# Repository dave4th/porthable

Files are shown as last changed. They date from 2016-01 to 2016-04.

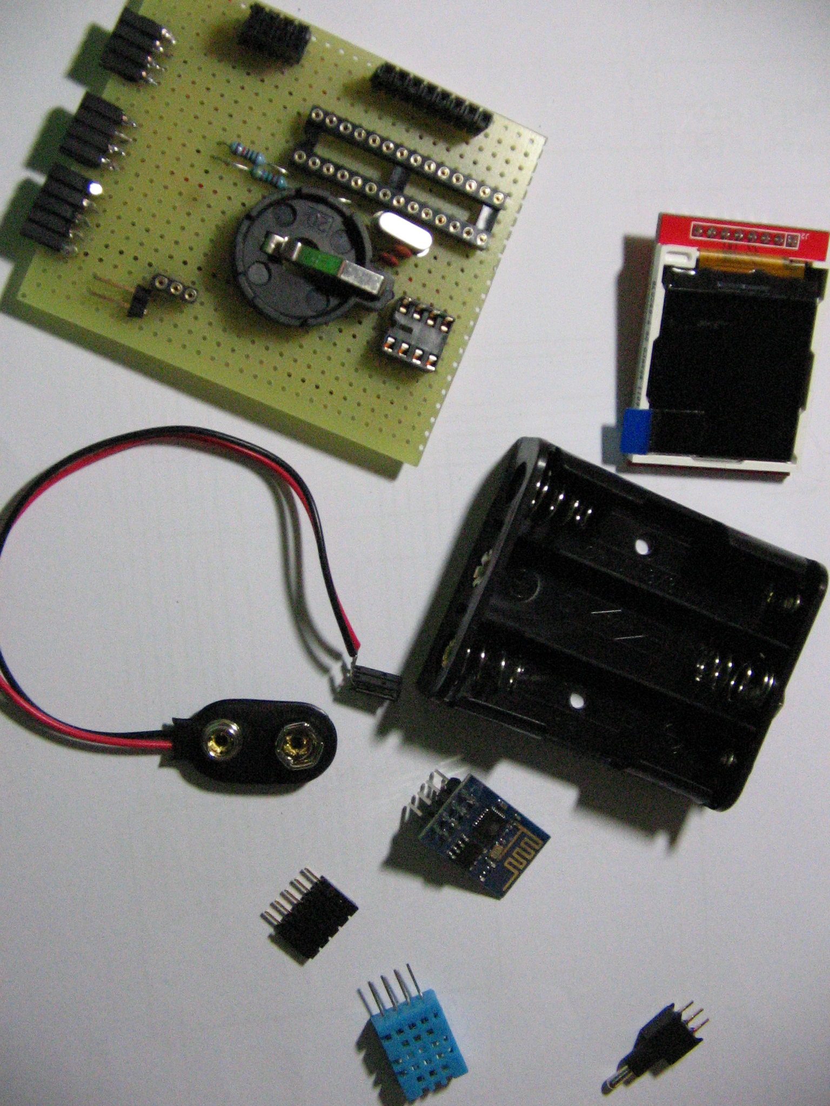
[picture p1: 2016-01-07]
foto/Porthable_beta_components_1.jpg

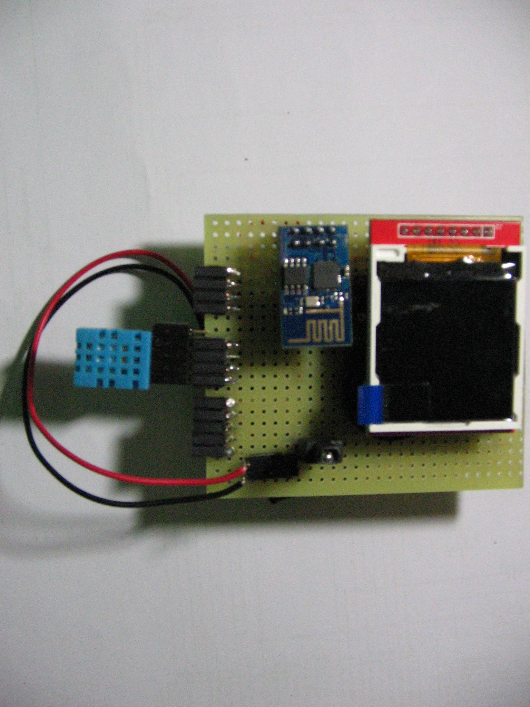
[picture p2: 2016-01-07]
foto/Porthable_beta_2nd_mount.jpg

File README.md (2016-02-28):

ATTENZIONE
==========
Il progetto e` in corso, le informazioni contenute in questo repository sono inesatte ed incomplete.

# porthable
Portabile (?) "logger" di temperatura e umidita` con LCD e mdulo ESP8266

Un piccolo esperimento per realizzare un sensore di temperatura che sia movibile per rilevazioni temporanee, che memorizzi le variazioni in un grafico e trasmetta o permetta di leggere da remoto i valori.

Poi .. vedremo in cosa e se .. si evolvera`.

## Composizione/i
* ATMEGA328P (Arduino)
* Sonda temperatura:
    * Sonda di temperatura e umidita` DHT11
    * Sonda di temperatura DS18B20
* TFT LCD 1,44"
* Modulo wifi ESP8266
* Modulo orologio DS1302

# Kicad

Il circuito e` aggiornato (se non ho dimenticato di fare upload ;) ), normalmente anche il ".pdf", per il resto, estrazione materiali, pcb .. eccetera, sono solo delle prove.

# w/ DS1302

Nei 'moduli' con orologio, per prima cosa si deve configurare l'ora, dopo aver collegato all'ATMEGA il DS1302 come da circuito elettrico, caricare sul microcontrollore il programma: "porthable_DS1302_SetSerial".

### Problema DS1302

Se si sostituisce l'atmega (per esempio quando se ne mette uno programmato differente) togliendo completamente alimentazione, lsciando comunque la batteria tampone, il DS1302 sembra vada in blocco e si deve riprogrammare.

Sembra sia sufficiente mantenere alimentazione (o meglio, mantenere il riferimento a 0V) aprendo solo l'interruttore di accensione, quando si sostituisce l'atmega.

## Programmazione con Raspberry Pi

Anzitutto ho creato il ".hex" semplicemente facendo un verifica dall'Arduino IDE 1.6.7, il file viene generato in una sottodirectory "/tmp".

Prima di caricare il programma, scollegate/togliete il Display (perche\` ha dei collegamenti in comune sulla SPI) e il modulo ESP8266 (perche\` e\` collegato sulla seriale), se li avete collegati.

Caricare lo sketch col comando (non serve avere un'ATMEGA col bootloader precaricato):
<pre>sudo avrdude -p m328p -P /dev/spidev0.0 -c linuxspi -b 10000 -U flash:w:git/porthable/arduino/porthable_DS1302_SetSerial.ino.hex</pre>

Con le "python-serial" (http://pyserial.readthedocs.org/en/latest/tools.html#module-serial.tools.miniterm) ho configurato l'ora:
<pre>miniterm.py --cr /dev/ttyAMA0 115200</pre>

Le istruzioni su come procedere all'impostazione dell'ora sono indicate nel ".ino" (che contiene il codice sorgente), comunque basta inserire la stringa "aaaa,mm,gg,HH,MM,SS" (Anno,Mese,Giorno,Hora,Minuti,Secondi).

Questa operazione dovra\` essere ripetuta quando si scarichera` la batteria tampone.

Ora potete procedere caricando sull'ATMEGA il programma vero e proprio ...

# porthable ADLD

Prima versione, composta da:
* ATMEGA328P
* DHT11
* LCD TFT 1,44"
* DS1302

Programmazione ATMEGA328P:
<pre><code>sudo avrdude -p m328p -P /dev/spidev0.0 -c linuxspi -b 10000 -U lfuse:w:0xFF:m -U hfuse:w:0xDE:m -U efuse:w:0x06:m</code></pre>
<pre><code>sudo avrdude -p m328p -P /dev/spidev0.0 -c linuxspi -b 10000 -U flash:w:porthable_adld.ino.hex</code></pre>

Il programma contiene ancora tutti i riferimenti alla configurazione completa, ma sono stati commentati i blocchi inutilizzati.

Lo schema elettrico comprende ancora tutta la circuiteria, e\` sufficiente non collegare quello che non c'e\` o che non si utilizza (vedi programma/sketch).

# porthable ADLE

Seconda versione, composta da:
* ATMEGA328P
* DHT11
* LCD TFT 1,44"
* ESP8266

Il programma e\` stato ampiamente rivisto, ma contiene ancora qualche riferimento alla configurazione completa, sono stati commentati i blocchi inutilizzati.

Lo schema elettrico comprende ancora tutta la circuiteria, e\` sufficiente non collegare quello che non c'e\` o che non si utilizza (vedi programma/sketch).

# porthable AWLD

Versione con sonda 'OneWire', composta da:
* ATMEGA328P
* DS18B20
* LCD TFT 1,44"
* DS1302

Solito, il programma e\` stato modificato mantenendo alcuni riferimenti alla configurazione da cui e\` stato originato (ADLE), sono stati commentati i blocchi inutilizzati.

Il collegamento della sonda 'OneWire' DS18B20 e\` identico al DHT11 (non ho ancora fatto o modificato uno schema elettrico)

Lo schema elettrico comprende ancora tutta la circuiteria, e\` sufficiente non collegare quello che non c'e\` o che non si utilizza (vedi programma/sketch).

# porthable AWLE

Versione con sonda 'OneWire', composta da:
* ATMEGA328P
* DS18B20
* LCD TFT 1,44"
* ESP8266

Solito, il programma e\` stato modificato mantenendo alcuni riferimenti alla configurazione da cui e\` stato originato (AWLE, AWLD), sono stati commentati i blocchi inutilizzati.

Il collegamento della sonda 'OneWire' DS18B20 e\` identico al DHT11 (non ho ancora fatto o modificato uno schema elettrico)

Lo schema elettrico comprende ancora tutta la circuiteria, e\` sufficiente non collegare quello che non c'e\` o che non si utilizza (vedi programma/sketch).

# Update

## Aggiornamenti 2016 01 24

Ho eliminato la seriale software, troppi problemi, collegando l'ESP sulla seriale standard dell'ATMEGA.

Ho aggiunto un potenziometro per selezionare/modificare i tempi di refresh del grafico.

Ho modificato la visualizzazione sul display,
 aggiungendo i tempi grafico e qualche tacca di riferimento,
 forse ho esagerato ..

Il programma testato e\` solamente quello della versione ADLE,
 nell'altro mi sono limitato a copiare le parti, quindi e\` da provare.

Modificato circuito elettrico.

Elimino i ".hex" dal repository github (sapete come ricavarli dai sorgenti ;) )

## Aggiornamenti 2016 01 31

Rimesso ".hex" per comodita\`.

## Aggiornamenti 2016 02 03

Cambiato libreria sensore DHT11 (http://playground.arduino.cc/Main/DHT11Lib).

Modificato aggiornamento data-ora.

Aggiunte memorie di lettura per eliminare le troppe oscillazioni sui valori.

Per ora solo versione ADLE.

# Riferimenti

* http://www.rinkydinkelectronics.com/library.php?id=5
* https://github.com/PaulStoffregen/OneWire

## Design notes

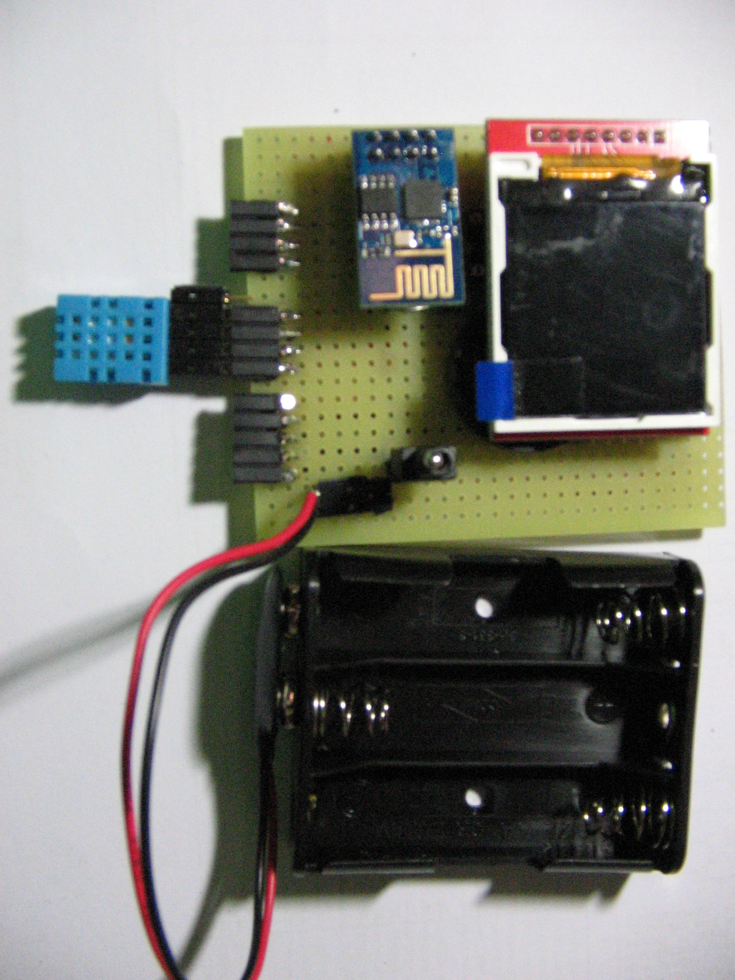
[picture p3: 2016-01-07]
foto/Porthable_beta_1st_mount.jpg

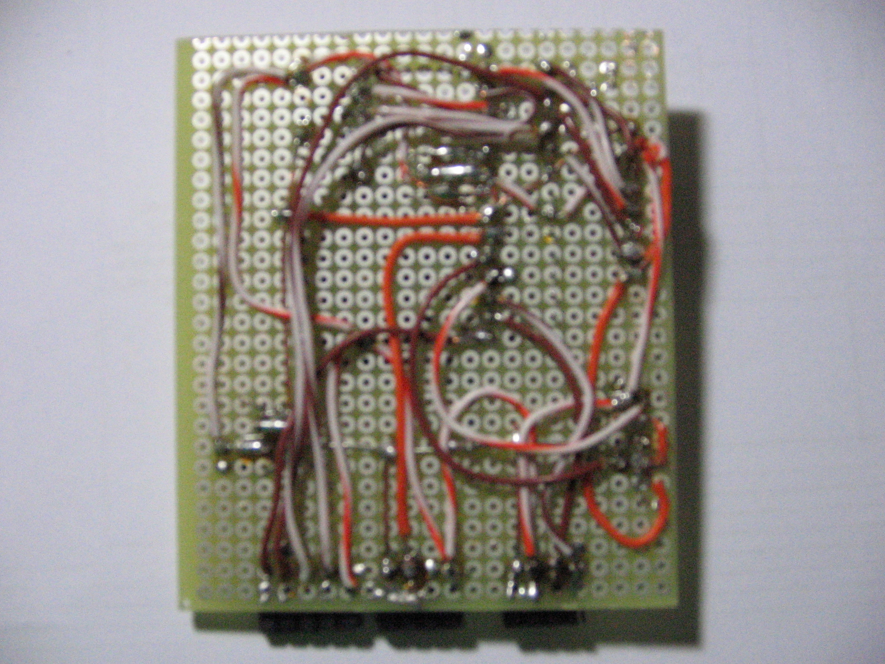
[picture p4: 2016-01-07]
foto/Porthable_beta_back.jpg

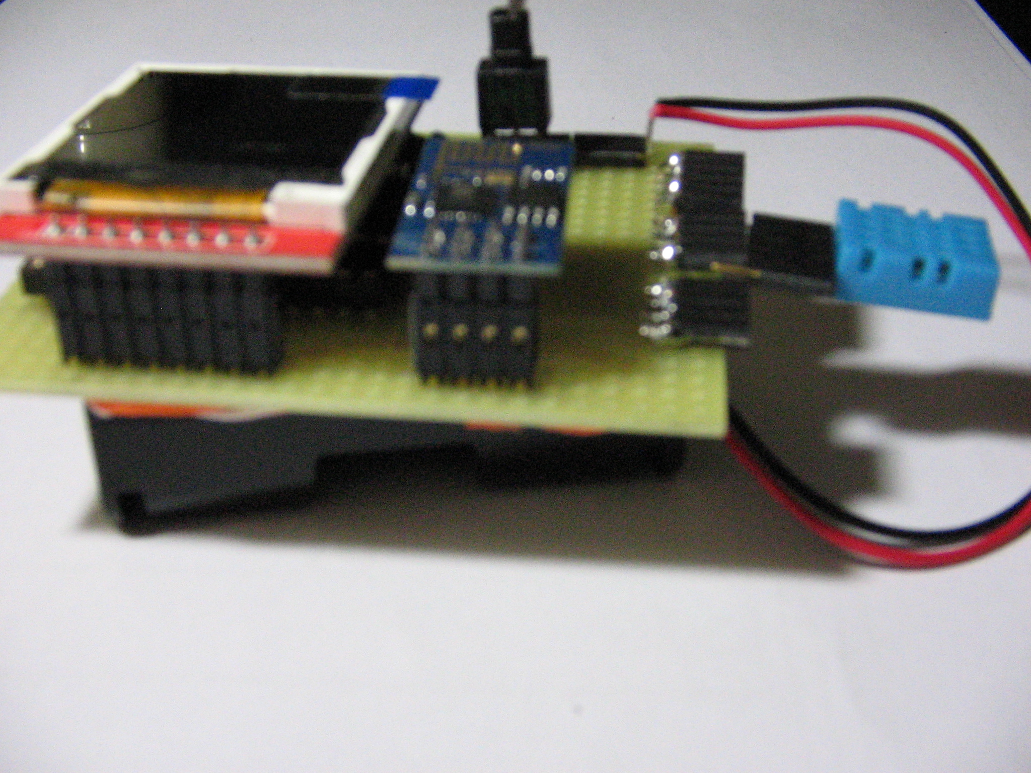
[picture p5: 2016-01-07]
foto/Porthable_beta_2nd_mount_lateral.jpg

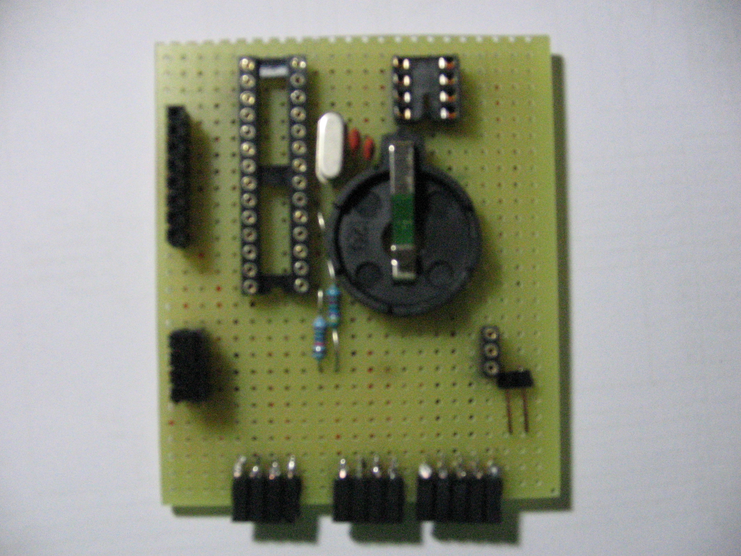
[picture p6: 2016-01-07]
foto/Porthable_beta_front.jpg

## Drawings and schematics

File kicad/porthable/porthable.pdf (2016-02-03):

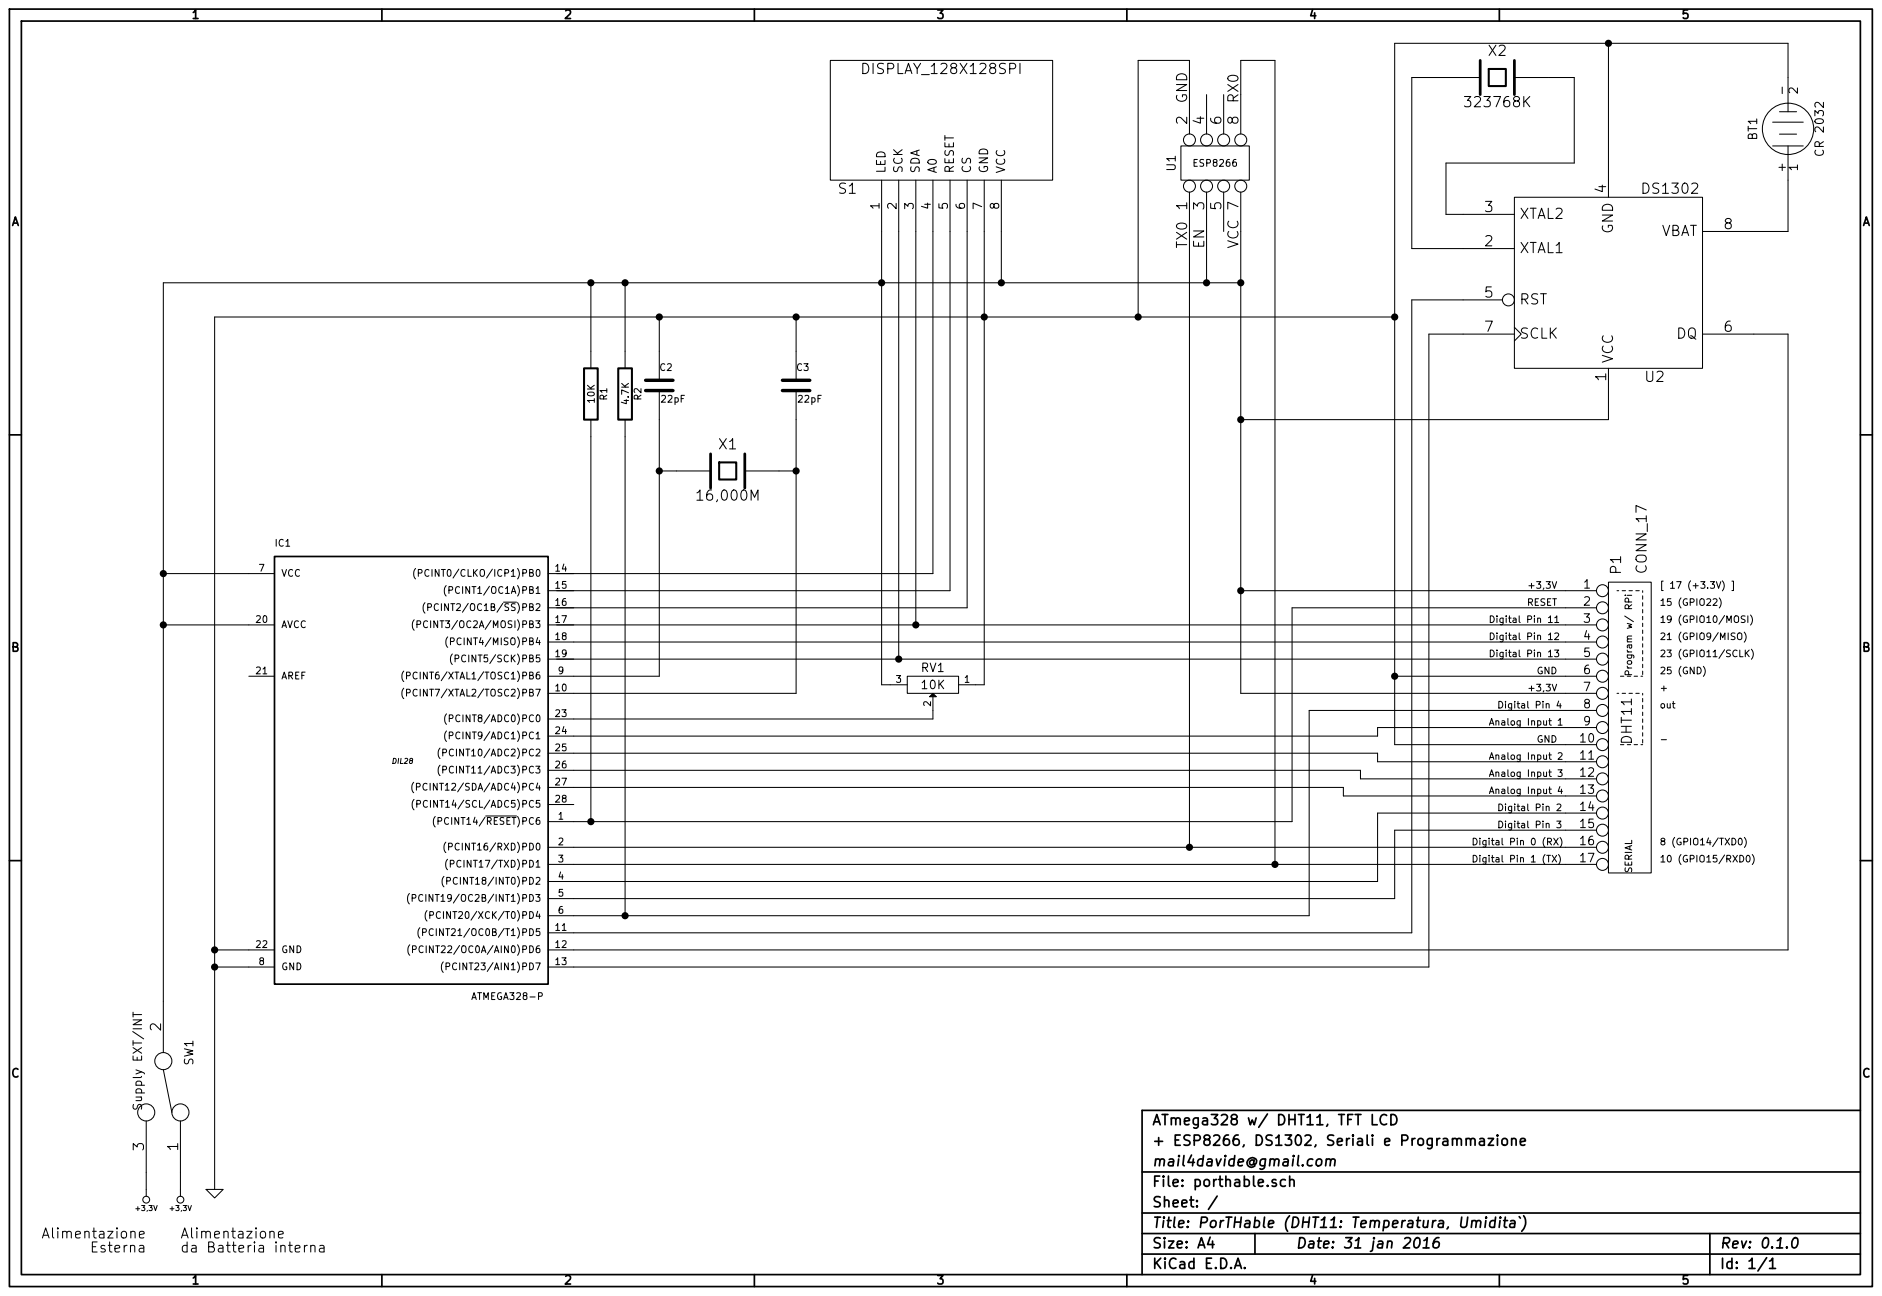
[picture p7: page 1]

out - Analog Input 1 Analog Input 2 Analog Input 3 Analog Input 4 Digital Pin 2 Digital Pin 3 Digital Pin 1 (TX) Digital Pin 0 (RX) RESET Digital Pin 11 Digital Pin 12 Digital Pin 13

+ ESP8266, DS1302, Seriali e Programmazione
mail4davide@gmail.com
File: porthable.sch
Sheet: /
Title: PorTHable (DHT11: Temperatura, Umidita`)
KiCad E.D.A.

da Batteria interna Alimentazione Esterna

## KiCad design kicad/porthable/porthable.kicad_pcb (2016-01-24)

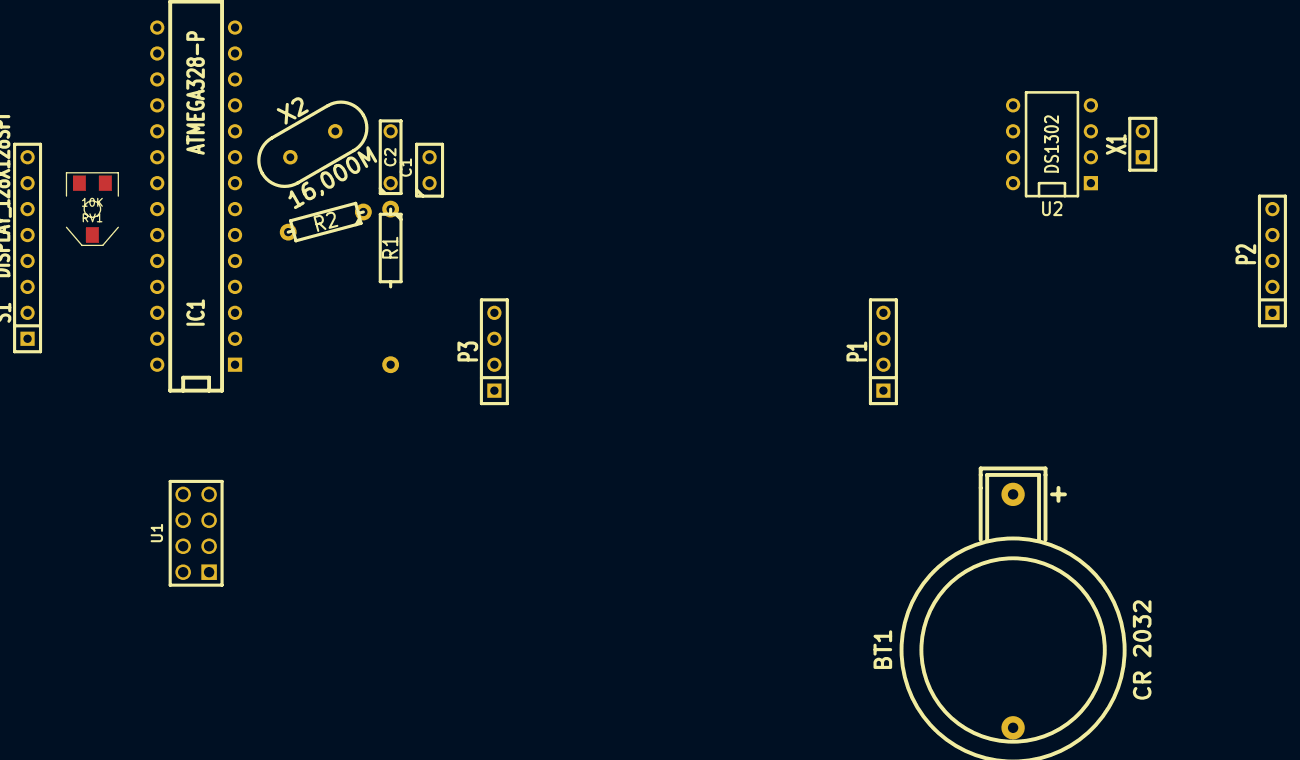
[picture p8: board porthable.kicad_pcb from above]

Board: 2 copper layers, 15 parts (0 on the bottom side), 20 nets, no tracks yet.

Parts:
BT1: CR 2032; CR2032H
C1: 22pF; C1
C2: 22pF; C2
IC1: ATMEGA328-P; DIP-28__300
P1: DHT11; SIL-4
P2: Program w/R.Pi; SIL-5
P3: Serial; SIL-4
R1: 10K; R3-LARGE_PADS
R2: 4.7K; R3-LARGE_PADS
RV1: 10K; POT_CMS
S1: DISPLAY_128X128SPI; SIL-8
U1: ESP8266; pin_array_4x2
U2: DS1302; DIP-8__300
X1: 323768K; SIL-2
X2: 16,000M; HC-49V

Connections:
GND: BT1.2, C1.1, C2.1, IC1.8, IC1.22, P1.4, P2.5, P3.2, RV1.1, S1.7, U1.2, U2.4
unnamed: IC1.18, P2.3
unnamed: IC1.2, P3.3
unnamed: IC1.3, P3.4
unnamed: U2.3, X1.2
unnamed: IC1.11, U2.5
unnamed: BT1.1, U2.8
unnamed: IC1.6, P1.2, R2.2
unnamed: U2.2, X1.1
unnamed: IC1.23, RV1.2
unnamed: IC1.13, U2.7
unnamed: IC1.4, U1.1
unnamed: IC1.12, U2.6
unnamed: IC1.5, U1.8
unnamed: IC1.7, IC1.20, P1.1, P3.1, R1.1, R2.1, RV1.3, S1.1, S1.8, U1.3, U1.7, U2.1
unnamed: P2.4, S1.2
unnamed: P2.2, S1.3
unnamed: C1.2, IC1.9, X2.1
unnamed: IC1.1, P2.1, R1.2
unnamed: C2.2, IC1.10, X2.2

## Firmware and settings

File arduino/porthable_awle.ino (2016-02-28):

/*
 * Programma per la lettura di una sonda di Temperatura.
 * Oltre alla visualizzazione su schermo TFT LCD dei valori in formato testo,
 * viene realizzato un grafico temporale, con l'ausilio di un ESP8266.
 * Tramite quest'ultimo, i dati delle letture verranno inviati ad un MQTT Broker.
 * 
 * Versione OneWire w/ MQTT: porthable AWLE
 * . ATMEGA
 * . DS18B20 (1 Wire)
 * . LCD TFT 1,44"
 * . ESP8266 su seriale standard arduino
 * . Potenziometro per regolazione tempi grafico
 */

#include <TFT.h>  // Arduino LCD library
//#include <SPI.h>
//#include <dht11.h>  // Cambio libreria
//#include <DS1302RTC.h>
//#include <Time.h>
//#include <SoftwareSerial.h> // ESP8266
#include <TimeLib.h>        // Libreria per gestione data/ora
#include <OneWire.h>

// TFT LCD
// pin definition for the LCD (Uno, Nano)
#define cs   10
#define dc   8
#define rst  9

// create an instance of the library
TFT TFTscreen = TFT(cs, dc, rst);

// DHT11, Sensore di temperatura e umidita`
//dht11 DHT;
//#define DHT11_PIN 4

OneWire  ds(4);  // on pin 4 (a 4.7K resistor is necessary)

//int ReadHumidity = 0;
float ReadTemperature = 0;
//int Humidity = 0;
float Temperature = 0;
//int MemReadHumidity = 0;
float MemReadTemperature = 0;
//int MemHumidity = 0;
float MemTemperature = 0;

// Init the DS1302
// Set pins:  CE, IO,CLK
//DS1302RTC RTC(5, 6, 7);

// ESP8266
//SoftwareSerial espSerial(2,3); // RX e` il 2,TX e` il 3, collegati a ESP8266

/*
 * Variabili accessorie per stampe sul display e memorizzazioni
 */
// char array to print to the screen, only Humidity & Temperature ?
char SensorTPrintout[6];
//char SensorHPrintout[3];
char DataPrintout[11];
char TimePrintout[9];

// e memorie ..
//char MemSensorHPrintout[6];
char MemSensorTPrintout[6];
char MemDataPrintout[11];
char MemTimePrintout[9];

int Day = 1;
int Month = 1;
int Year = 2016;
int Hours = 1;
int Minutes = 1;
int Seconds = 1;
int MemSeconds = 0;
int MemMinutes = 1;
int MemHours = 0; // Aggiunta per aggiornamento dell'orario (che non funziona bene ?)
int MemDay = 0;

// int array per creazione grafico
/*
 * Ho dovuto usare degli interi, sia per limitare l'uso di memoria
 * che per ragioni pratiche di stampa del grafico tramite accensione
 * dei pixel dello schermo LCD
 */
int ArrayTemperature[128];
//int ArrayHumidity[128];
int CycleArray = 0; // Valori ciclici da 0 a 127

//Variabili per Potenziometro
int PotPin = A0;
int PotValue = 0;
int TimeGraph = 0;
int MemTimeGraph = 0;
char TimeGraphPrintout[3];
char MemTimeGraphPrintout[3];
// e Grafico
char TotalTimeGraphPrintout[5];
char MemTotalTimeGraphPrintout[5];


void writeTextStatic() {
  /*
   * Le lettere sono alte 7 e larghe 5
   * Quindi considerare 6 di occupazione orizzontale
  */ 
  // write the static text to the screen
  // set the font color to gray
  TFTscreen.stroke(128, 128, 128);
  // set the font size
  TFTscreen.setTextSize(1);
  // write the text to the top left corner of the screen
  // write the text
  TFTscreen.text("Data       Ora", 0, 0);
  // write the text
  TFTscreen.text("Temperatura", 0, 24);
  // write the text
  TFTscreen.text("Campionamento", 0, 48);
  // write the text
  TFTscreen.text("min.", 103, 48);
  // write the text
  TFTscreen.text("In memoria", 0, 56);
  // write the text
  TFTscreen.text("min.", 103, 56);
  /*
   * Volevo mettere delle tacche, ha senso ?
   * .. write ..
   */
  TFTscreen.stroke(64, 64, 64);  // gray 75%
  //TFTscreen.text("50 -  -  -  -  -  -  -", 0, 69);
  TFTscreen.text("40 -  -  -  -  -  -  -", 0, 79);
  TFTscreen.text("30 -  -  -  -  -  -  -", 0, 89);
  TFTscreen.text("20 -  -  -  -  -  -  -", 0, 99);
  TFTscreen.text("10 -  -  -  -  -  -  -", 0, 109);
  TFTscreen.text("0", 0, 119);
  
  // set the font color to white
  TFTscreen.stroke(128, 128, 128);
  // set the font size
  TFTscreen.setTextSize(2);
  // write the text
  //TFTscreen.text("%\n ", 103, 16);
  // write the text
  //TFTscreen.text("C\n ", 103, 32);  // Non lo metto, per ragioni "estetiche"
  
}

/*
 * Era usata dalla RTC, non serve ora.
void print2digits(int number) {
  if (number >= 0 && number < 10)
    Serial.write('0');
  Serial.print(number);
}
 */

void setup() {

  /*
  * Visto che si avvia sempre con orario 1970 ....
  * fisso una data che permetta il corretto funzionamento,
  * altrimenti il grafico inizia sempre all'accensione,
  * mentre deve rispettare la mezz'ora impostata.
  * 
  * setTime(Ora,Minuti,Secondi,Giorno,Mese,Anno);
  */
  setTime(Hours,Minutes,Seconds,Day,Month,Year); // alternative to above, yr is 2 or 4 digit yr (2010 or 10 sets year to 2010)

  // Setup Serial connection
  Serial.begin(9600);

  //Serial.println("Serial.begin(9600)");

  // Setup serial ESP8266
  //espSerial.begin(9600);
  //Serial.println("espSerial.begin(9600)");

  //espSerial.setTimeout(15000);
  
/*
  Serial.println("DS1302RTC Read Test");
  Serial.println("-------------------");
  
  // Activate RTC module
  Serial.println("RTC module activated");
  Serial.println();
  delay(500);
  
  if (RTC.haltRTC()) {
    Serial.println("The DS1302 is stopped.  Please run the SetTime");
    Serial.println("example to initialize the time and begin running.");
    Serial.println();
  }
  if (!RTC.writeEN()) {
    Serial.println("The DS1302 is write protected. This normal.");
    Serial.println();
  }
*/

  // TFT
  // Put this line at the beginning of every sketch that uses the GLCD:
  TFTscreen.begin();

  // clear the screen with a black background
  TFTscreen.background(0, 0, 0);

  writeTextStatic();
  
  delay(2000);
  //Serial.println("* END setup! *");

}

void loop() {

  //Serial.println("* Start LOOP *");
/*
  //RTC
  tmElements_t tm;
  
  Serial.print("UNIX Time: ");
  Serial.print(RTC.get());

  if (! RTC.read(tm)) {
    Serial.print("  Time = ");
    print2digits(tm.Hour);
    Serial.write(':');
    print2digits(tm.Minute);
    Serial.write(':');
    print2digits(tm.Second);
    Serial.print(", Date (D/M/Y) = ");
    Serial.print(tm.Day);
    Serial.write('/');
    Serial.print(tm.Month);
    Serial.write('/');
    Serial.print(tmYearToCalendar(tm.Year));
    Serial.print(", DoW = ");
    Serial.print(tm.Wday);
    Serial.println();
  } else {
    Serial.println("DS1302 read error!  Please check the circuitry.");
    Serial.println();
    delay(9000);
  }
*/

/* Ho eliminato totalmente la parte DHT11 */

  /* DS18x20 */
  byte i;
  byte present = 0;
  byte type_s;
  byte data[12];
  byte addr[8];
  float celsius, fahrenheit;
  
  if ( !ds.search(addr)) {
    //Serial.println("No more addresses.");
    //Serial.println();
    ds.reset_search();
    delay(250);
    return;
  }
  
  //Serial.print("ROM =");
  //for( i = 0; i < 8; i++) {
  //  Serial.write(' ');
  //  Serial.print(addr[i], HEX);
  //}

  //if (OneWire::crc8(addr, 7) != addr[7]) {
  //    Serial.println("CRC is not valid!");
  //    return;
  //}
  //Serial.println();
 
  // the first ROM byte indicates which chip
  switch (addr[0]) {
    case 0x10:
      //Serial.println("  Chip = DS18S20");  // or old DS1820
      type_s = 1;
      break;
    case 0x28:
      //Serial.println("  Chip = DS18B20");
      type_s = 0;
      break;
    case 0x22:
      //Serial.println("  Chip = DS1822");
      type_s = 0;
      break;
    default:
      //Serial.println("Device is not a DS18x20 family device.");
      return;
  } 

  ds.reset();
  ds.select(addr);
  ds.write(0x44, 1);        // start conversion, with parasite power on at the end
  
  delay(1000);     // maybe 750ms is enough, maybe not
  // we might do a ds.depower() here, but the reset will take care of it.
  
  present = ds.reset();
  ds.select(addr);    
  ds.write(0xBE);         // Read Scratchpad

  //Serial.print("  Data = ");
  //Serial.print(present, HEX);
  //Serial.print(" ");
  for ( i = 0; i < 9; i++) {           // we need 9 bytes
    data[i] = ds.read();
    //Serial.print(data[i], HEX);
    //Serial.print(" ");
  }
  //Serial.print(" CRC=");
  //Serial.print(OneWire::crc8(data, 8), HEX);
  //Serial.println();

  // Convert the data to actual temperature
  // because the result is a 16 bit signed integer, it should
  // be stored to an "int16_t" type, which is always 16 bits
  // even when compiled on a 32 bit processor.
  int16_t raw = (data[1] << 8) | data[0];
  if (type_s) {
    raw = raw << 3; // 9 bit resolution default
    if (data[7] == 0x10) {
      // "count remain" gives full 12 bit resolution
      raw = (raw & 0xFFF0) + 12 - data[6];
    }
  } else {
    byte cfg = (data[4] & 0x60);
    // at lower res, the low bits are undefined, so let's zero them
    if (cfg == 0x00) raw = raw & ~7;  // 9 bit resolution, 93.75 ms
    else if (cfg == 0x20) raw = raw & ~3; // 10 bit res, 187.5 ms
    else if (cfg == 0x40) raw = raw & ~1; // 11 bit res, 375 ms
    //// default is 12 bit resolution, 750 ms conversion time
  }
  celsius = (float)raw / 16.0;
  fahrenheit = celsius * 1.8 + 32.0;
  //Serial.print("  Temperature = ");
  //Serial.print(celsius);
  //Serial.print(" Celsius, ");
  //Serial.print(fahrenheit);
  //Serial.println(" Fahrenheit");
/* END */

ReadTemperature = celsius;

  /*
   * Visto che il valore letto e` incostante, aggiungo un ciclo di conferma 
   * prima di memorizzare:
   * 
   * Se temperatura letta divera, 
   * e se la memoria e` diversa da quella in lettura ..
   * memorizzo,
   * se e` uguale,
   * metto la memoria in "valore ok"
   */
/*
  if (ReadHumidity != Humidity) {
    if (MemReadHumidity != ReadHumidity) {
      MemReadHumidity = ReadHumidity;
    }
    else {
      Humidity = MemReadHumidity;
    }
  }
*/
  if (ReadTemperature != Temperature) {
    if (MemReadTemperature != ReadTemperature) {
      MemReadTemperature = ReadTemperature;
    }
    else {
      Temperature = MemReadTemperature;
    }
  }
  /* Fine controllo e memorizzazione nuovi valori */

  // DISPLAY DATA
  //Serial.print(Humidity, 1);
  //Serial.print(",\t");
  //Serial.println(Temperature, 1);

  // LCD
  // Read the value from DHT11
  //String sensorValH = String(Humidity);
  String sensorValT = String(Temperature);
  
  // convert the reading to a char array
  //sensorValH.toCharArray(SensorHPrintout, 3);
  sensorValT.toCharArray(SensorTPrintout, 6);

  // Gestione DATA/ORA proveniente da ESP8266 via seriale
  while (Serial.available() > 0) {
    String inString = Serial.readStringUntil('\n');
    //Serial.println(inString);
    // Se la stringa inizia per ... la riga successiva conterra` la data e ora
    if (inString.startsWith("Date:")) {
      Day = Serial.parseInt();
      Month = Serial.parseInt();
      Year = Serial.parseInt();
      Hours = Serial.parseInt();
      Minutes = Serial.parseInt();
      Seconds = Serial.parseInt();
      //Serial.println(now());
    }
    // Ogni ora aggiorno ..
  }
  
  if (Hours != MemHours) {
    setTime(Hours,Minutes,Seconds,Day,Month,Year); // alternative to above, yr is 2 or 4 digit yr (2010 or 10 sets year to 2010)
    MemHours = Hours;
  }

  /*
   * Queste le devo comunque eseguire ..
   * servono per la conversione in stringa e la stampa sul display
   * (Ho messo i "." come la stringa dell'ESP)
   */
  String DataVal1 = String(year());
  String DataVal2 = String(DataVal1 + "." + month());
  String DataValDay = String(DataVal2 + "." + day());
  String DataVal3 = String(hour());
  String DataVal4 = String(DataVal3 + ":" + minute());
  String DataValTime = String(DataVal4 + ":" + second());
  DataValDay.toCharArray(DataPrintout, 11);
  DataValTime.toCharArray(TimePrintout, 9);
  
  // set the font size for date/time
  TFTscreen.setTextSize(1);

  // Date/time
  /*
   *  Se valore e` diverso dalla memoria,
   *  [ri]scrivo la memoria e poi il valore,
   *  poi metto la memoria uguale al valore
   */
  if (Day != MemDay) {
    /*Serial.print("Compare: ");
    Serial.print(MemDataPrintout);
    Serial.print(" - ");
    Serial.println(DataPrintout);*/
    // erase the text you just wrote
    TFTscreen.stroke(0, 0, 0);
    TFTscreen.text(MemDataPrintout, 0, 8);
    // set the font color
    TFTscreen.stroke(255, 255, 0);
    // print
    TFTscreen.text(DataPrintout, 0, 8);
    // Memorie
    MemDay = Day;
    strcpy (MemDataPrintout, DataPrintout);
  }

  /*
   * L'utilizzo dei secondi non e` propriamente corretto, perche` potrebbe
   * per pura coincidenza, ripetersi un cambio lettura al medesimo "secondo"
   * ma di un minuto/i successivo/i .. solo che non funziona la comparazione
   * fra le stringhe ..
   */
  if (second() != MemSeconds) {
    /*Serial.print("Compare: ");
    Serial.print(MemTimePrintout);
    Serial.print(" - ");
    Serial.println(TimePrintout);*/
    // erase the text you just wrote
    TFTscreen.stroke(0, 0, 0);
    TFTscreen.text(MemTimePrintout, 66, 8);
    // set the font color
    TFTscreen.stroke(255, 255, 0);
    // print
    TFTscreen.text(TimePrintout, 66, 8);
    // Memorie
    MemSeconds = second();
    strcpy (MemTimePrintout, TimePrintout);
  }

  // set the font size for humidity/temperature
  TFTscreen.setTextSize(2);

/*
  // Humidity
  if (Humidity != MemHumidity) {
    // erase the text you just wrote
    TFTscreen.stroke(0, 0, 0);
    TFTscreen.text(MemSensorHPrintout, 76, 16);
    // set the font color
    TFTscreen.stroke(0, 255, 0);
    // print the sensor value
    TFTscreen.text(SensorHPrintout, 76, 16);
    MemHumidity = Humidity;
    strcpy (MemSensorHPrintout, SensorHPrintout);
  }
*/

  // Temperature
  if (Temperature != MemTemperature) {
    // erase the text you just wrote
    TFTscreen.stroke(0, 0, 0);
    TFTscreen.text(MemSensorTPrintout, 66, 32);
    // set the font color
    TFTscreen.stroke(255, 0, 0);
    // print the sensor value
    TFTscreen.text(SensorTPrintout, 66, 32);  // era 76, lo metto in colonna con l'ora
    Serial.println(SensorTPrintout); // ESP8266
    MemTemperature = Temperature;
    strcpy (MemSensorTPrintout, SensorTPrintout);
  }

  // set the font size for potentiometer
  TFTscreen.setTextSize(1);

  /*
   * Inserisco qua la gestione del potenziometro e del grafico
   */
  PotValue = analogRead(PotPin);
  TimeGraph = map(PotValue,0,1023,1,31);  // da 1 a 30 minuti, ho dovuto restringere il campo causa sensibilita` potenziometro
  // Potenziometro
  String stringTimeGraph = String(TimeGraph);
  // convert the reading to a char array
  stringTimeGraph.toCharArray(TimeGraphPrintout, 3);
  // Grafico
  String stringTimeGraph128 = String(TimeGraph * 128);
  // convert the reading to a char array
  stringTimeGraph128.toCharArray(TotalTimeGraphPrintout, 5);
  if (TimeGraph != MemTimeGraph) {
    // erase the text you just wrote
    TFTscreen.stroke(0, 0, 0);
    TFTscreen.text(MemTimeGraphPrintout, 88, 48);
    TFTscreen.text(MemTotalTimeGraphPrintout, 76, 56);
    // set the font color
    TFTscreen.stroke(0, 0, 255);
    // print the sensor value
    TFTscreen.text(TimeGraphPrintout, 88, 48);
    TFTscreen.text(TotalTimeGraphPrintout, 76, 56);
    MemTimeGraph = TimeGraph;
    strcpy (MemTimeGraphPrintout, TimeGraphPrintout);
    strcpy (MemTotalTimeGraphPrintout, TotalTimeGraphPrintout);
  }

  /*
   * Devo stare attento perche` questa routine dev'essere eseguita
   * una sola volta, quindi: ATTENZIONE alle condizioni!
   * 
   * Aggiorno ogni X-minuto/i non m'interessa da quando ho acceso,
   * preferisco sia "fisso", come i termostati in casa ..
   * 
   * Aggiorna una sola volta nello stesso minuto, 
   * e aggiorna solo se la divisione non da` resto
   */
  if (minute() != MemMinutes && (minute() % TimeGraph == 0)) {
    // Stampa array su LCD
    /*
    * Stampa i 128 (come i pixel) valori di temperatura e umidita`,
    * creando un grafico.
    * Al solito, devo prima eliminare la scritta precedente 
    * e poi mettere la nuova.
    * 
    * Scrivo da sinistra a destra, quindi devo partire dal piu` "alto" e scendere (sottrarre)
    * L'aggiornamento dell'array invece, posso farlo normalmente.
    * Introduzione i valori negativi nella scala, predispongo per un -5 massimo,
    * quindi devo sottrarre 5 ai valori "punto" da stampare, perche devo 'alzare' il punto,
    * perche` shiftero` in alto il grafico.
    */
    // Prima cancello le scritte
    TFTscreen.stroke(0, 0, 0);
    for (CycleArray = 127; CycleArray >= 0; CycleArray--) {
      //TFTscreen.point(CycleArray, 127 - ArrayHumidity[CycleArray]);
      TFTscreen.point(CycleArray, 127 - ArrayTemperature[CycleArray] - 5 ); // Potevo cambiare 127, ma per chiarezza ...
    }
    // Poi shifto e aggiorno con l'ultimo valore
    for (CycleArray = 0; CycleArray <= 126; CycleArray++) {
      //ArrayHumidity[CycleArray] = ArrayHumidity[CycleArray+1];
      ArrayTemperature[CycleArray] = ArrayTemperature[CycleArray+1];
    }
    // Quando finisce e` al 127 e posso scrivere il dato nuovo
    //ArrayHumidity[CycleArray] = Humidity;
    ArrayTemperature[CycleArray] = int(Temperature);  // Intero perche` tanto il grafico non gestisce i numeri con la virgola
    // Memorizzo il tempo attuale
    MemMinutes = minute();
    // Scrivo ..
    for (CycleArray = 127; CycleArray >= 0; CycleArray--) {
      //TFTscreen.stroke(0, 255, 0);
      //TFTscreen.point(CycleArray, 127 - ArrayHumidity[CycleArray]);
      TFTscreen.stroke(255, 0, 0);
      TFTscreen.point(CycleArray, 127 - ArrayTemperature[CycleArray] - 5 ); // Anche qua, ovviamente il "- 5"
    }
  }

  /*
   * Mi sa che i delay serva per la stabilita` delle letture
   * Cerco di tenerlo il piu` basso possibile, a 200 funziona, metto 300 per sicurezza
   */
  delay(300);
}

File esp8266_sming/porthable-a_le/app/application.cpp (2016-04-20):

#include <user_config.h>
#include <SmingCore/SmingCore.h>

// If you want, you can define WiFi settings globally in Eclipse Environment Variables
#ifndef WIFI_SSID
	//#define WIFI_SSID "PleaseEnterSSID" // Put you SSID and Password here
	//#define WIFI_PWD "PleaseEnterPass"
#endif

// ... and/or MQTT username and password
#ifndef MQTT_USERNAME
	#define MQTT_USERNAME ""
	#define MQTT_PWD ""
#endif

// ... and/or MQTT host and port
#ifndef MQTT_HOST
	#define MQTT_HOST "level1"
	#define MQTT_PORT 1883
#endif

/* (My) User settings */
#define MQTT_PUBLISH "I/Mobile/Mobile/porthable/Temperatura"	// Percorso di pubblicazione dei dati MQTT
#define MQTT_SUBSCRIBE "O/Mobile/Mobile/porthable/#"	// Percorso di lettura dei dati MQTT
#define ID "TEMPmobile"	// Identificatore
#define NTP_SERVER   "0.it.pool.ntp.org"	// Indirizzo del sever NTP
#define FTP_USERNAME "me"			// Username FTP
#define FTP_PASSWORD "123"			// Password FTP

// Mi serve per stamparla sulla pagina web
String Temperatura;
// Usata solo per la stampa RTC che ho disattivato
//Timer printTimer;

// Forward declarations
void startMqttClient();
void onMessageReceived(String topic, String message);
void onDataCallback(Stream& stream, char arrivedChar, unsigned short availableCharsCount);

// MQTT client
// For quickly check you can use: http://www.hivemq.com/demos/websocket-client/ (Connection= test.mosquitto.org:8080)
MqttClient mqtt(MQTT_HOST, 1883, onMessageReceived);

// Questa serve all'elenco delle reti WiFi
BssList networks;

HttpServer server;
FTPServer ftp;

/***	NTP	***/
void onNtpReceive(NtpClient& client, time_t timestamp);

// Option 1
// Use this option if you want to have full control of NtpTime client
// Default : no automatic NTP requests sent, no automatic update of SystemTime
// Default : NTP_DEFAULT_SERVER and NTP_DEFAULT_AUTO_UPDATE_INTERVAL from ntpclient.h
// NtpClient ntpClient(onNtpReceive);

// Option 2
// Use this option if you want control but other server/timeout options
// Default : use server as defined in call, no automatic update of SystemTime
// Default : automatic NTP request at myRequestInterval seconds
// Default : if myRequestInterval == 0 -> no automatic NTP request
NtpClient ntpClient (NTP_SERVER, 8 * 60 * 60, onNtpReceive);	// 8 ore, * 60 minuti, * 60 secondi

// Option 3
// Use this option if you want to start wit autorefresh and autosystemupdate
// No further callback from ntpClient
// NtpClient ntpClient("pool.ntp.org", 30);

// Option 4
// only create pointer and initialize on ConnectOK
// NtpClient *ntpClient;


// Callback example using defined class ntpClientDemo
//ntpClientDemo *demo;

// CallBack example 1 
// ntpClientDemo dm1 = ntpClientDemo();
// or use 
// ntpClientDemo dm1;
/*	NTP	*/


// Legge lo stream della seriale e lo mette sulla variabile "Message" come stringa
// Credo che questa funzione sia in un ".h/.cpp" del framework. Funziona ? La uso ;)
// Aggiungo l'invio del dato al broker mqtt.
void onDataCallback(Stream& stream, char arrivedChar, unsigned short availableCharsCount)
{
    String Message = "";  // Inizializzo stringa da inviare al broker mqtt
    if (arrivedChar == '\n')
    {
	//Serial.println("<New line received>");			// Ho dovuto eliminare tutti i messaggi alla seriale
	while (stream.available())
        {
            char cur = stream.read();
            //Serial.print(cur);
            Message += cur;   // Aggiunge caratteri (cur) alla stringa
        }

    Message.remove(Message.length()-2);   // Elimino dalla stringa i caratteri "\" e "n", perche` inviano un CR

    // Non sono sicuro che funzioni, e` da provare!

    if (mqtt.getConnectionState() != eTCS_Connected)
        startMqttClient(); // Auto reconnect

    // Promemoria
    //Serial.println("* PROMEMORIA *");
    //Serial.println("Sottoscrizione a: main/status/#");
    //Serial.println("Pubblicazione sul topic: porthable/adle/message");
    //Serial.println("-----------------------------------------------");

    //Serial.println("Let's publish message now!");
    //mqtt.publish(MQTT_PUBLISH, String(SystemClock.getSystemTimeString(eTZ_UTC)+","+Message)); // or publishWithQoS	// Prima di "level 1"
	mqtt.publish(MQTT_PUBLISH, "{ \"ID\" : \"" + String(ID) + "\", \"Valore\" : \"" + String(Message) + "\" }"); // or publishWithQoS
    //Serial.println(Temperatura);	// Usata per verifica temperatura
    Temperatura = Message;	// Copia stringa per stampa
    //Serial.println(Temperatura);	// Usata per verifica temperatura

    // Queste le metto per leggerle dall'ATMEGA ('data e ora' attuali)
    Serial.println("Date:");	// Mi serve un prefisso di riconoscimento
    Serial.println(SystemClock.getSystemTimeString(eTZ_UTC));
    }
}


// Callback for messages, arrived from MQTT server
void onMessageReceived(String topic, String message)
{
	Serial.print(topic);
	Serial.print(":\r\n\t"); // Prettify alignment for printing
	Serial.println(message);
}

// Run MQTT client
void startMqttClient()
{
	if(!mqtt.setWill("last/will","The connection from this device is lost:(", 1, true)) {
		debugf("Unable to set the last will and testament. Most probably there is not enough memory on the device.");
	}
	mqtt.connect("esp8266");
	mqtt.subscribe("main/status/#");
}

/*
void onPrintSystemTime() {
	Serial.print("Local Time    : ");
	Serial.println(SystemClock.getSystemTimeString());
	Serial.print("UTC Time: ");
	Serial.println(SystemClock.getSystemTimeString(eTZ_UTC));
}
*/

// Called when time has been received by NtpClient (option 1 or 2)
// Either after manual requestTime() or when
// and automatic request has been made.
void onNtpReceive(NtpClient& client, time_t timestamp) {
	SystemClock.setTime(timestamp);

	Serial.print("Time synchronized: ");
	Serial.println(SystemClock.getSystemTimeString());
}
/*	NTP	*/


/*	WEB/FTP Servers	*/
void onIndex(HttpRequest &request, HttpResponse &response)
{
	TemplateFileStream *tmpl = new TemplateFileStream("index.html");
	auto &vars = tmpl->variables();
	//vars["counter"] = String(counter);
	response.sendTemplate(tmpl); // this template object will be deleted automatically
}

void onFile(HttpRequest &request, HttpResponse &response)
{
	String file = request.getPath();
	if (file[0] == '/')
		file = file.substring(1);

	if (file[0] == '.')
		response.forbidden();
	else
	{
		response.setCache(86400, true); // It's important to use cache for better performance.
		response.sendFile(file);
	}
}


void onAjaxSerial(HttpRequest &request, HttpResponse &response)
{
	JsonObjectStream* stream = new JsonObjectStream();
	JsonObject& json = stream->getRoot();
	json["status"] = (bool)true;
	json["value"] = SystemClock.getSystemTimeString((eTZ_UTC));

	response.sendJsonObject(stream);
}
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

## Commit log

2015-12-12 In funzione da 1 ora
    [porthable.sch]
2015-12-12 Update circuit diagram
2016-01-07 New ADLE
    [porthable.sch]
2016-01-24 + Potenziometro, Indicazioni grafiche
    [porthable.kicad_pcb, porthable.sch]
2016-02-03 Memorie lettura, sincronizzazione data-ora, circuito elettrico
    [porthable.sch]
2016-04-20 Data a MQTT di Livello 1
